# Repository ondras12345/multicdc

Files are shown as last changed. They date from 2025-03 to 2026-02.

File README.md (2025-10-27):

# MultiCDC
This is a simple RP2040-based 6-channel USB to UART converter.

This is my first project using the Zephyr RTOS, so there might be lots of
mistakes. However, it seems to work.

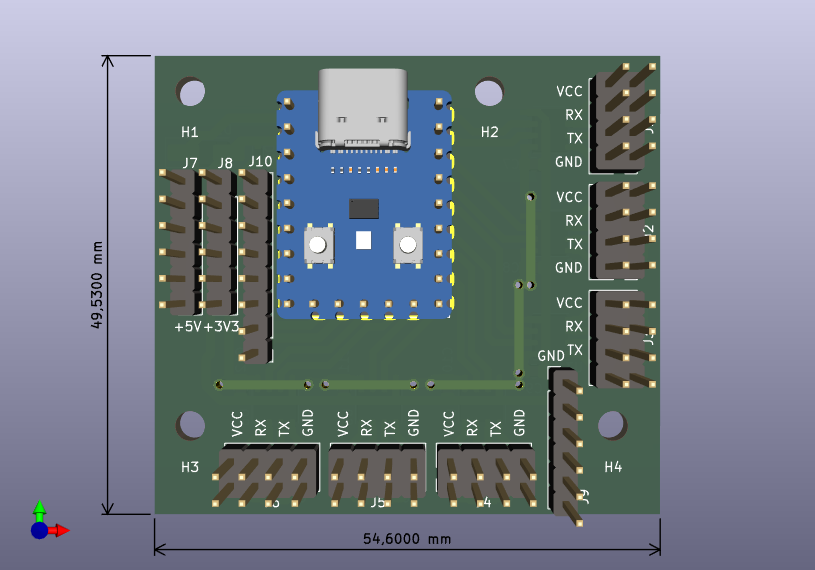
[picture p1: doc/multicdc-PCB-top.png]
top side of the MultiCDC pcb

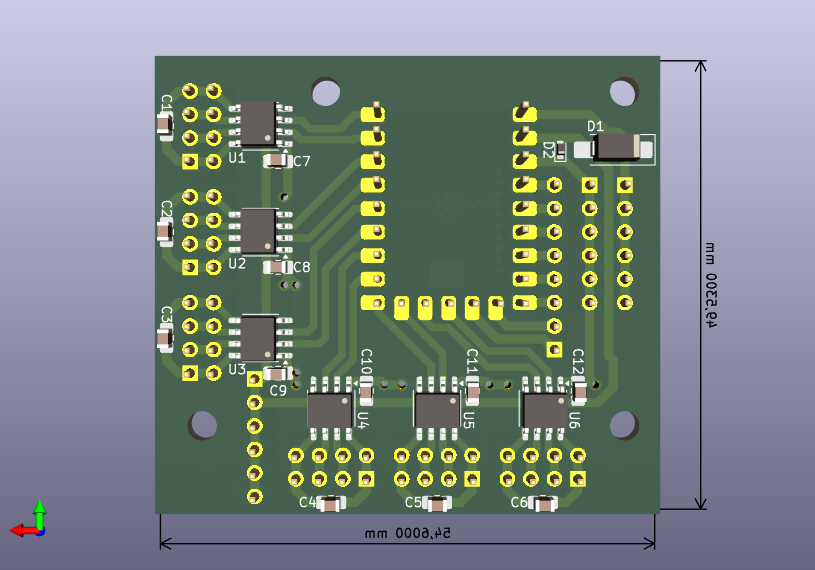
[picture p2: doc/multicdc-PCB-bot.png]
bottom side of the MultiCDC pcb


## Operation
The device creates 7 `/dev/ttyACM*` devices when connected to a linux host.
The first 6 are linked to hardware UARTs, and `/dev/ttyACM6` is used for
logging and shell.

The RP2040 only has 2 hardware UARTs. The other 4 channels use the PIOs.

Unfortunately, the `pico-uart-pio` driver doesn't allow changing the baud
rate at runtime. For this reason, baud rates (`current-speed`) for those
channels need to be set in the device tree (`app.overlay`).

Pin map (most of these can be changed arbitrarily):
| pin | function |
|:---:|:---:|
| P0  | Tx0 |
| P1  | Rx0 |
| P2  | Tx1 |
| P3  | Rx1 |
| P4  | Tx2 |
| P5  | Rx2 |
| P6  | Tx3 |
| P7  | Rx3 |
| P8  | Tx4 |
| P9  | Rx4 |
| P10 | Tx5 |
| P11 | Rx5 |

## Build
```sh
. ~/zephyrproject/.venv/bin/activate
. ~/zephyrproject/zephyr/zephyr-env.sh
west build

# enter bootloader: press BOOT button, press & release RESET, release BOOT
west flash
```

## Udev rules
```sh
sudo tee /etc/udev/rules.d/99-multicdc.rules > /dev/null << "EOF"
SUBSYSTEM=="tty", ENV{ID_VENDOR_ID}=="2fe3", ENV{ID_MODEL_ID}=="6cdc", ENV{ID_USB_INTERFACE_NUM}=="00", SYMLINK+="tty-mcdc0ch0"
SUBSYSTEM=="tty", ENV{ID_VENDOR_ID}=="2fe3", ENV{ID_MODEL_ID}=="6cdc", ENV{ID_USB_INTERFACE_NUM}=="02", SYMLINK+="tty-mcdc0ch1"
SUBSYSTEM=="tty", ENV{ID_VENDOR_ID}=="2fe3", ENV{ID_MODEL_ID}=="6cdc", ENV{ID_USB_INTERFACE_NUM}=="04", SYMLINK+="tty-mcdc0ch2"
SUBSYSTEM=="tty", ENV{ID_VENDOR_ID}=="2fe3", ENV{ID_MODEL_ID}=="6cdc", ENV{ID_USB_INTERFACE_NUM}=="06", SYMLINK+="tty-mcdc0ch3"
SUBSYSTEM=="tty", ENV{ID_VENDOR_ID}=="2fe3", ENV{ID_MODEL_ID}=="6cdc", ENV{ID_USB_INTERFACE_NUM}=="08", SYMLINK+="tty-mcdc0ch4"
SUBSYSTEM=="tty", ENV{ID_VENDOR_ID}=="2fe3", ENV{ID_MODEL_ID}=="6cdc", ENV{ID_USB_INTERFACE_NUM}=="0a", SYMLINK+="tty-mcdc0ch5"
SUBSYSTEM=="tty", ENV{ID_VENDOR_ID}=="2fe3", ENV{ID_MODEL_ID}=="6cdc", ENV{ID_USB_INTERFACE_NUM}=="0c", SYMLINK+="tty-mcdc0shell"
EOF

sudo udevadm control --reload-rules
sudo udevadm trigger
```

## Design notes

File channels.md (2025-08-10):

| channel | can change baudrate | baudrate  | voltage | device |
|:---:|:---:|---:|---:|:---|
| CH0 | yes | 38400 | 5V | lab-io (needs bootloader) |
| CH1 | no | 9600 | 5V | alarmclock |
| CH2 | yes | 115200 | ext | window-closer (bootloader)|
| CH3 | no | 9600 | 5V | ZPH02 |
| CH4 | no | 9600 | 3V3 | S88 (needs 5V power) |
| CH5 | no | 115200 | | reserved |

window-closer could teoretically go through a PIO channel now that we use
115200 baud both for the firmware and the bootloader, but avrdude upload via
pio was extremely unreliable.

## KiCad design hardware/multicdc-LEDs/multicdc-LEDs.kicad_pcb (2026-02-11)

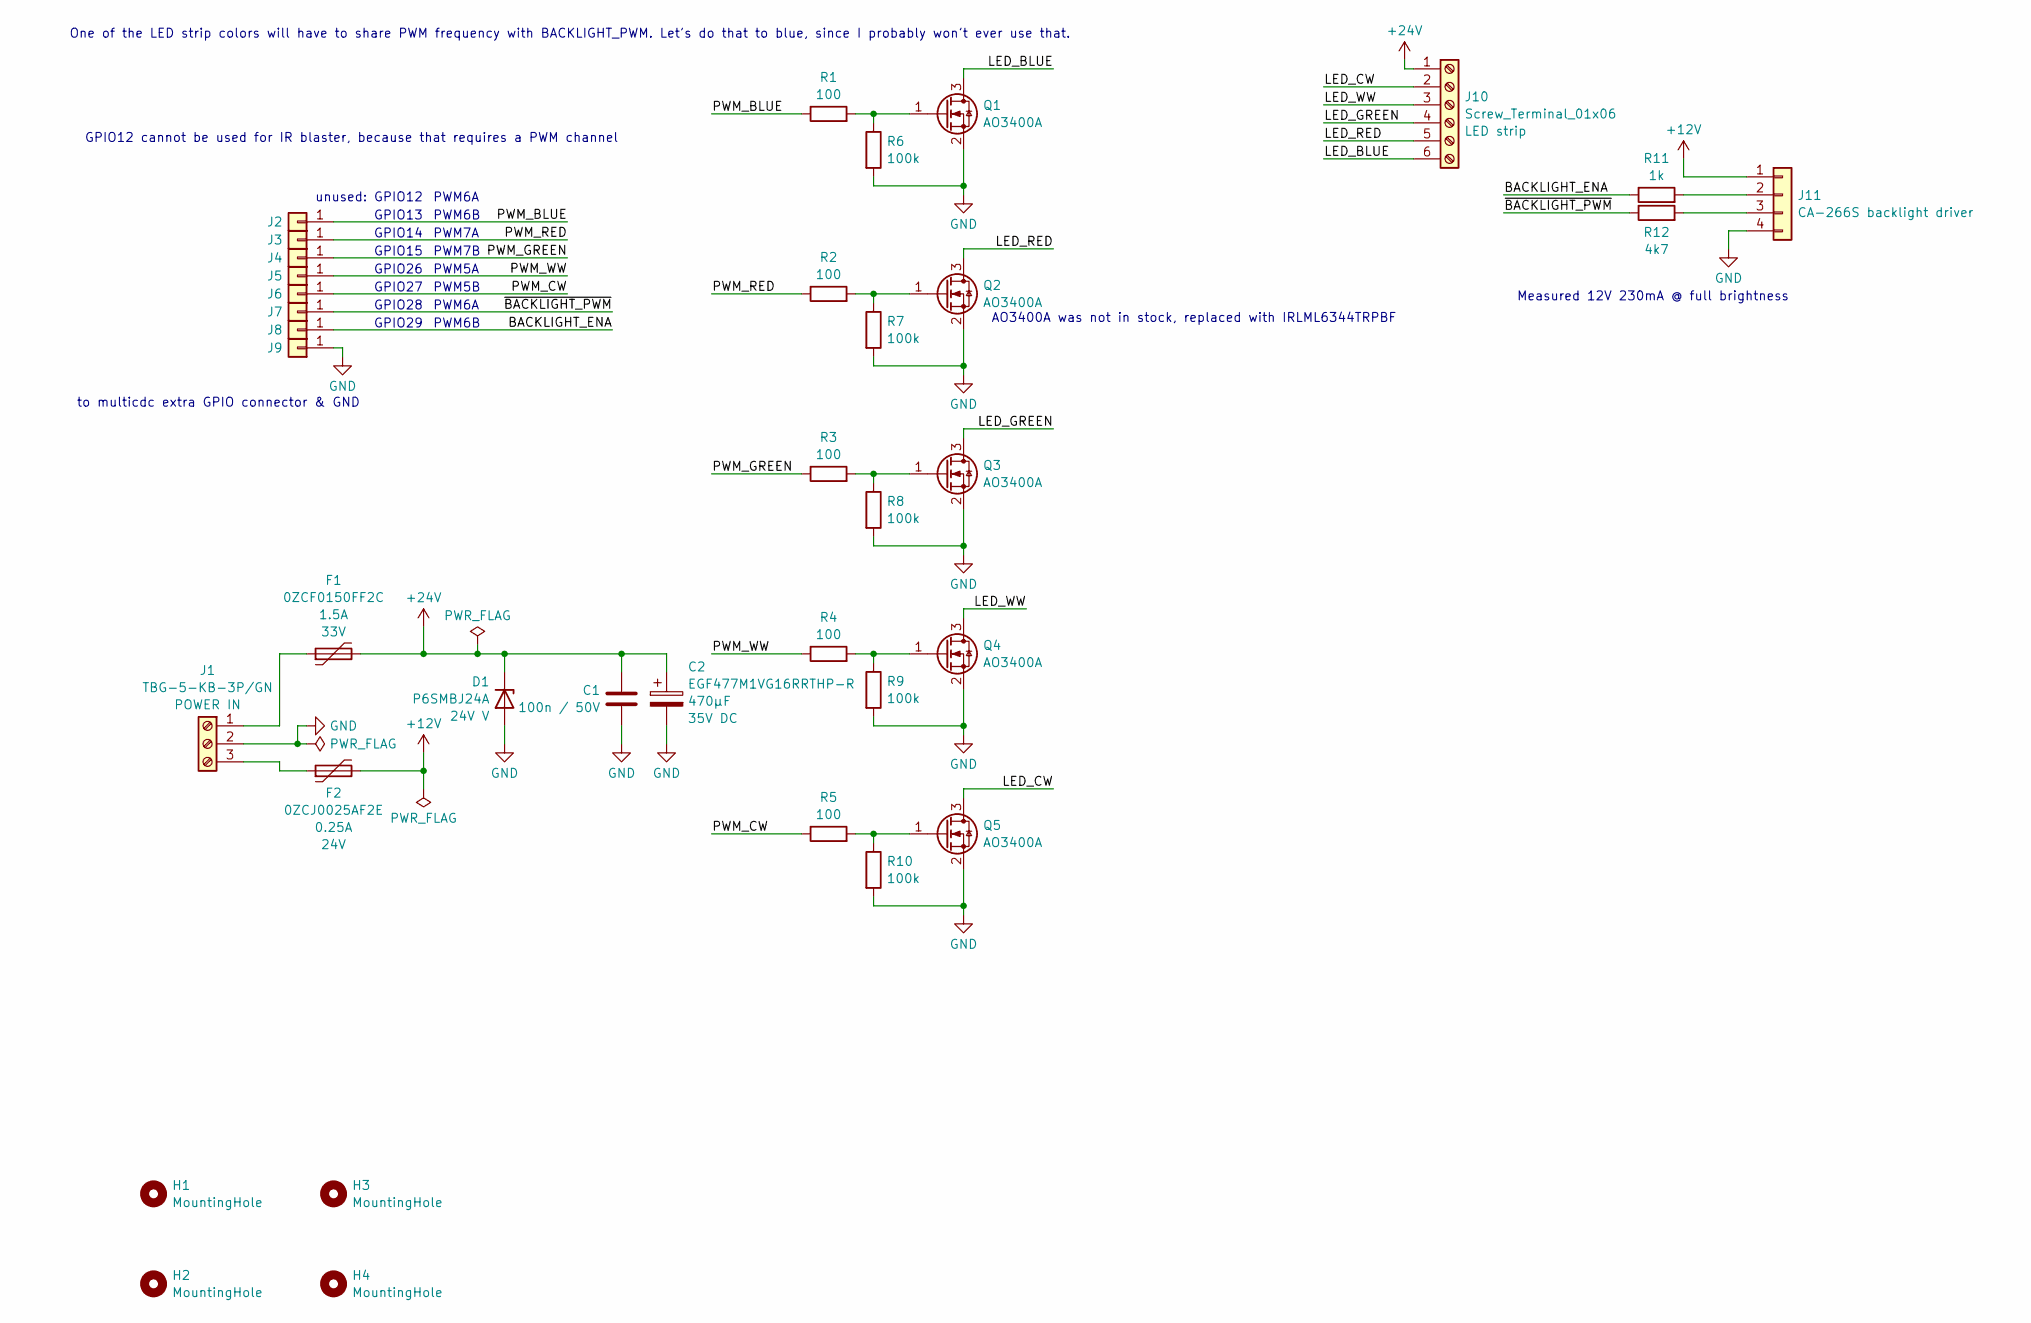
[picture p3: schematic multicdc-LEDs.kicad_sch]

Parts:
C1: 100n / 50V; C_1206_3216Metric_Pad1.33x1.80mm_HandSolder
C2: EGF477M1VG16RRTHP-R; CP_Radial_D10.0mm_P5.00mm; Tolerance 20% %; Rated Voltage 35V DC
D1: P6SMBJ24A; D_SMB_Handsoldering; Forward Voltage 26.7...29.6V; Standoff Voltage 24V V
F1: 0ZCF0150FF2C; Fuse_2920_7451Metric_Pad2.10x5.45mm_HandSolder; Rated Voltage 33V
F2: 0ZCJ0025AF2E; Fuse_1206_3216Metric_Pad1.42x1.75mm_HandSolder; Rated Voltage 24V
H1, H2, H3, H4: MountingHole; MountingHole_3.2mm_M3
J1: TBG-5-KB-3P/GN; TBG-5-KB-3P_1x03_P5.08mm_Horizontal; Rated Voltage 0.3kV
J2, J3, J4, J5, J6, J7, J8, J9: Conn_01x01; SolderWire-0.25sqmm_1x01_D0.65mm_OD1.7mm_Relief
J10: Screw_Terminal_01x06; TerminalBlock_Xinya_XY301VA-5.00-6P_1x06_P5.00mm_Horizontal
J11: soldered wires; SolderWire-0.25sqmm_1x04_P4.2mm_D0.65mm_OD1.7mm_Relief
Q1, Q2, Q3, Q4, Q5: AO3400A; SOT-23; Rated Voltage 30V
R1, R2, R3, R4, R5: 100; R_0805_2012Metric_Pad1.20x1.40mm_HandSolder
R6, R7, R8, R9, R10: 100k; R_0805_2012Metric_Pad1.20x1.40mm_HandSolder
R11: 1k; R_0805_2012Metric_Pad1.20x1.40mm_HandSolder
R12: 4k7; R_0805_2012Metric_Pad1.20x1.40mm_HandSolder

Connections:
+12V: F2.2, J11.1
+24V: C1.1, C2.1, D1.1 (K), F1.2, J10.1
/BACKLIGHT_ENA: J8.1, R11.1
/LED_BLUE: J10.6, Q1.3 (D)
/LED_CW: J10.2, Q5.3 (D)
/LED_GREEN: J10.4, Q3.3 (D)
/LED_RED: J10.5, Q2.3 (D)
/LED_WW: J10.3, Q4.3 (D)
/PWM_BLUE: J2.1, R1.1
/PWM_CW: J6.1, R5.1
/PWM_GREEN: J4.1, R3.1
/PWM_RED: J3.1, R2.1
/PWM_WW: J5.1, R4.1
/~BACKLIGHT_PWM: J7.1, R12.1
GND: C1.2, C2.2, D1.2 (A), J1.2, J9.1, J11.4, Q1.2 (S), Q2.2 (S), Q3.2 (S), Q4.2 (S), Q5.2 (S), R6.2, R7.2, R8.2, R9.2, R10.2
unnamed: F1.1, J1.1
unnamed: F2.1, J1.3
unnamed: J11.2, R11.2
unnamed: J11.3, R12.2
unnamed: Q1.1 (G), R1.2, R6.1
unnamed: Q2.1 (G), R2.2, R7.1
unnamed: Q3.1 (G), R3.2, R8.1
unnamed: Q4.1 (G), R4.2, R9.1
unnamed: Q5.1 (G), R5.2, R10.1

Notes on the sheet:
Measured 12V 230mA @ full brightness
GPIO15
GPIO27
GPIO29
GPIO26
unused: GPIO12
PWM5B
PWM6B
PWM7B
PWM5A
GPIO13
AO3400A was not in stock, replaced with IRLML6344TRPBF
One of the LED strip colors will have to share PWM frequency with BACKLIGHT_PWM. Let's do that to blue, since I probably won't ever use that.
to multicdc extra GPIO connector & GND
PWM7A
GPIO14
PWM6A
GPIO28
GPIO12 cannot be used for IR blaster, because that requires a PWM channel

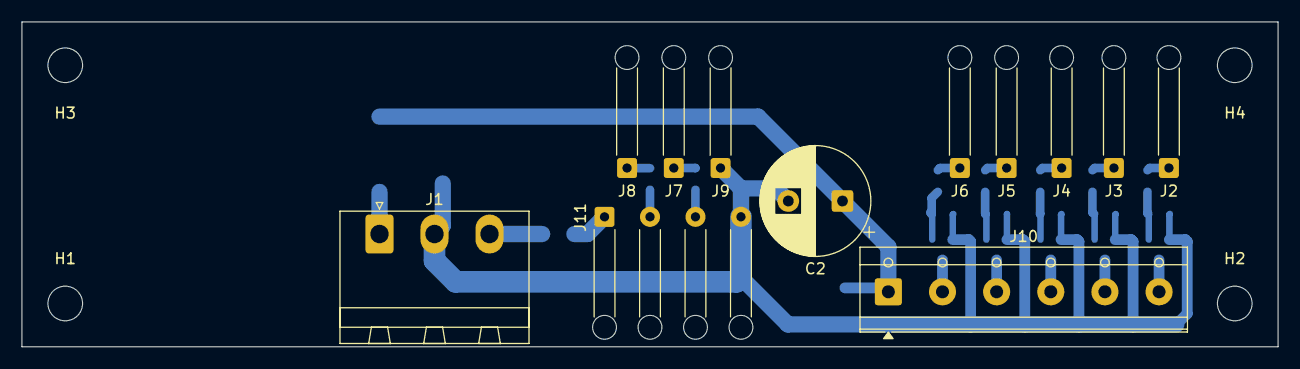
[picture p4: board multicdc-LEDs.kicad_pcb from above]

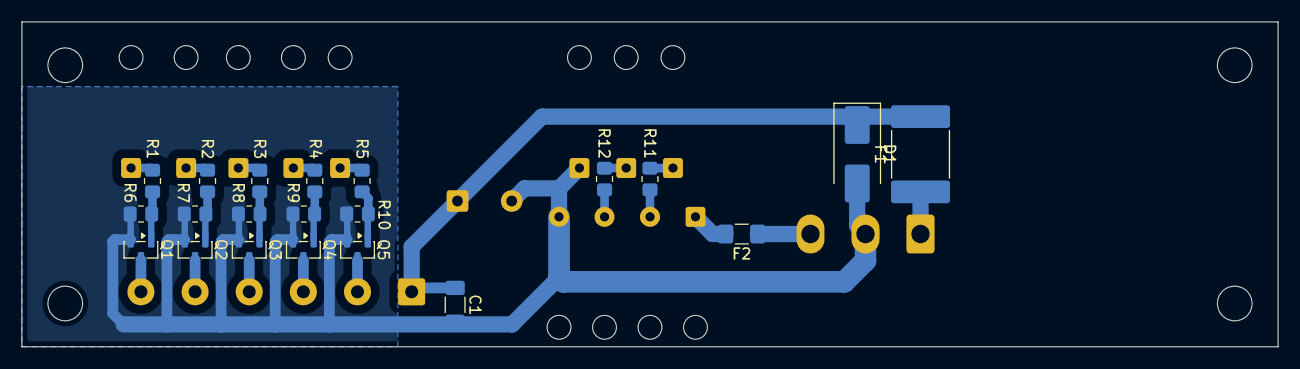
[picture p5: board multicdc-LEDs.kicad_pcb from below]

Board: 2 copper layers, 116.0 x 30.0 mm, 37 parts (21 on the bottom side), 24 nets.

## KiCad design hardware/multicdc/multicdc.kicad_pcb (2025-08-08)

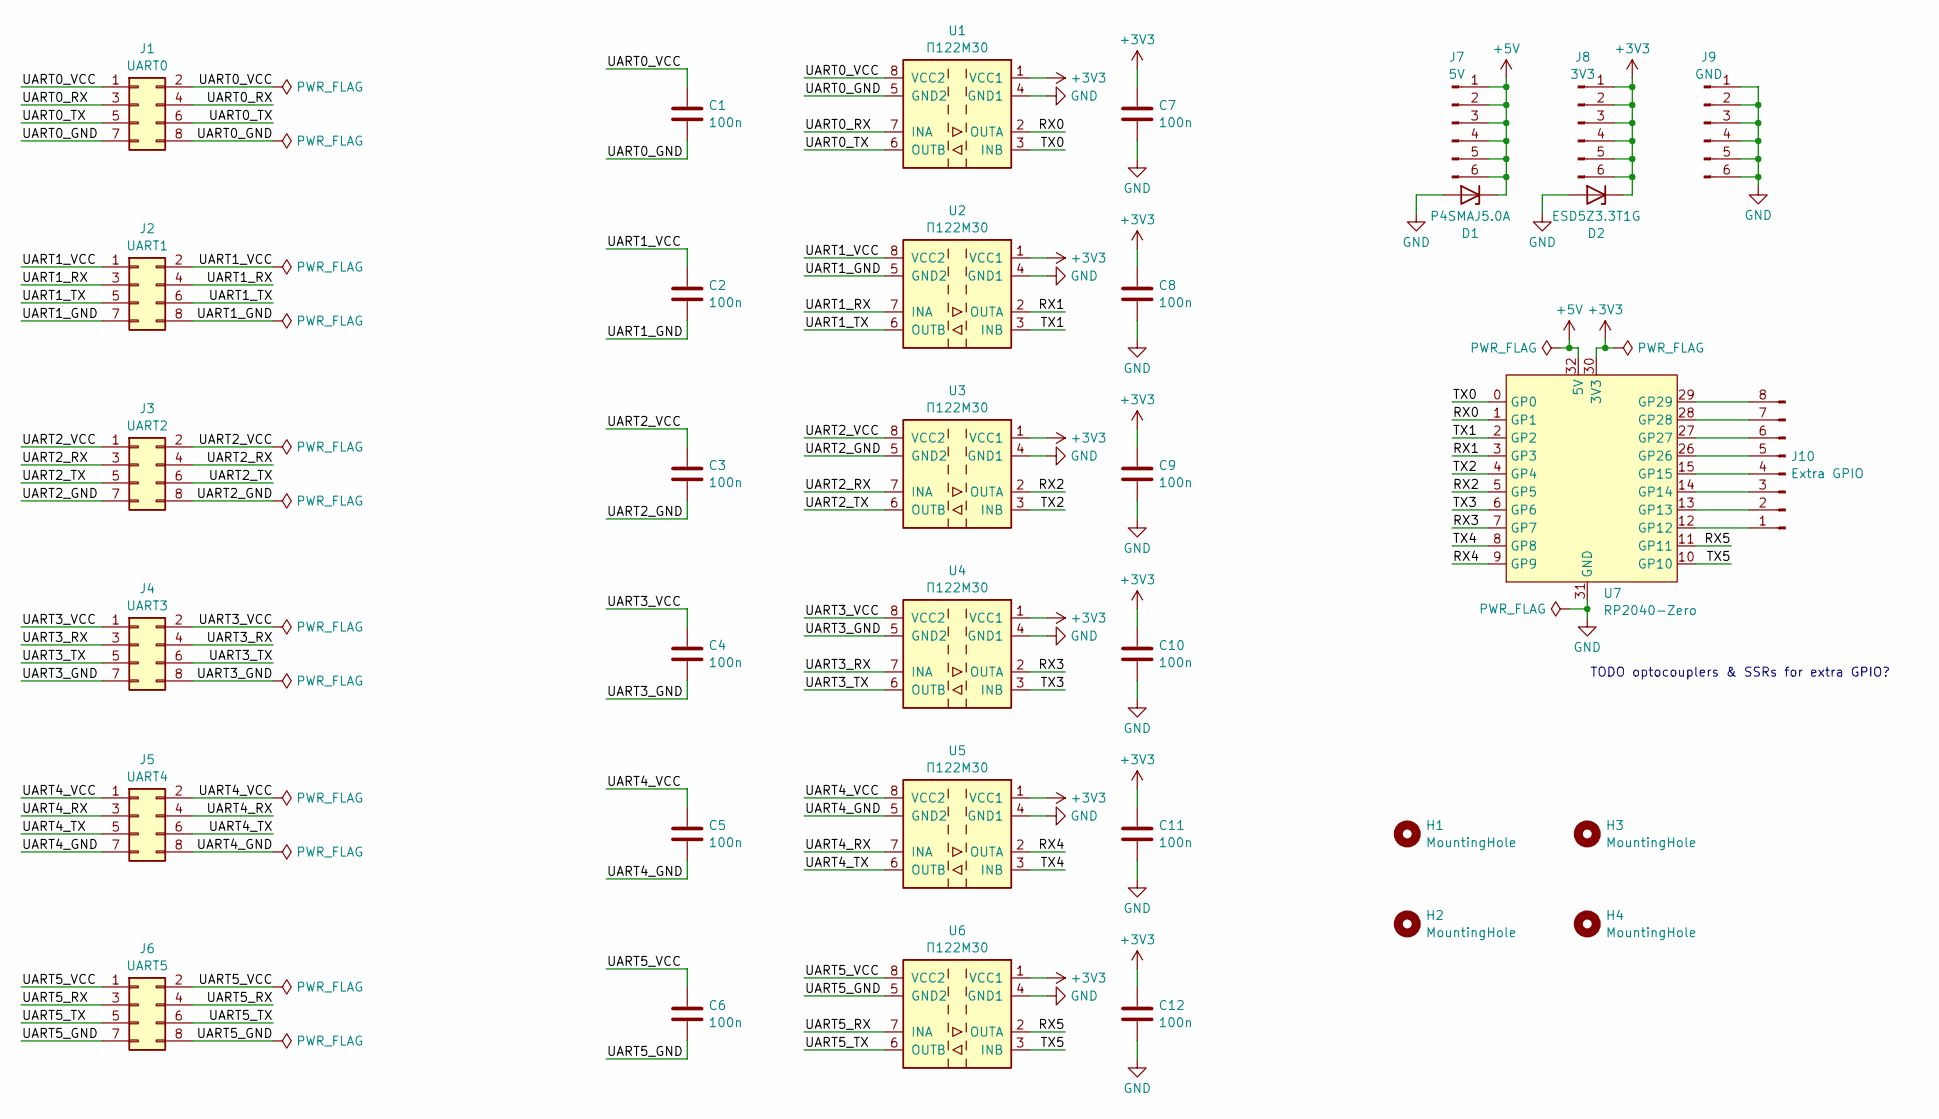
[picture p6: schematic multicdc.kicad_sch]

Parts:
C1, C2, C3, C4, C5, C6, C7, C8, C9, C10, C11, C12: 100n; C_0805_2012Metric_Pad1.18x1.45mm_HandSolder
D1: P4SMAJ5.0A; D_SMA_Handsoldering; Forward Voltage 6.4...7V; Standoff Voltage 5V
D2: ESD5Z3.3T1G; D_SOD-523; Forward Voltage 5V; Standoff Voltage 3.3V
H1, H2, H3, H4: MountingHole; MountingHole_3.2mm_M3
J1, J2, J3, J4, J5, J6: Conn_02x04_Odd_Even; PinHeader_2x04_P2.54mm_Vertical
J7, J8, J9: Conn_01x06_Pin; PinHeader_1x06_P2.54mm_Vertical
J10: Conn_01x08_Pin; PinHeader_1x08_P2.54mm_Vertical
U1, U2, U3, U4, U5, U6: Π122M30; SOIC-8_3.9x4.9mm_P1.27mm; Supply Voltage 3...5.5V DC
U7: RP2040-Zero

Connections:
+3V3: C7.1, C8.1, C9.1, C10.1, C11.1, C12.1, D2.1 (K), J8.1, J8.2, J8.3, J8.4, J8.5, J8.6, U1.1 (VCC1), U2.1 (VCC1), U3.1 (VCC1), U4.1 (VCC1), U5.1 (VCC1), U6.1 (VCC1), U7.30 (3V3)
+5V: D1.1 (K), J7.1, J7.2, J7.3, J7.4, J7.5, J7.6, U7.32 (5V)
/RX0: U1.2 (OUTA), U7.1 (GP1)
/RX1: U2.2 (OUTA), U7.3 (GP3)
/RX2: U3.2 (OUTA), U7.5 (GP5)
/RX3: U4.2 (OUTA), U7.7 (GP7)
/RX4: U5.2 (OUTA), U7.9 (GP9)
/RX5: U6.2 (OUTA), U7.11 (GP11)
/TX0: U1.3 (INB), U7.0 (GP0)
/TX1: U2.3 (INB), U7.2 (GP2)
/TX2: U3.3 (INB), U7.4 (GP4)
/TX3: U4.3 (INB), U7.6 (GP6)
/TX4: U5.3 (INB), U7.8 (GP8)
/TX5: U6.3 (INB), U7.10 (GP10)
/UART0_GND: C1.2, J1.7, J1.8, U1.5 (GND2)
/UART0_RX: J1.3, J1.4, U1.7 (INA)
/UART0_TX: J1.5, J1.6, U1.6 (OUTB)
/UART0_VCC: C1.1, J1.1, J1.2, U1.8 (VCC2)
/UART1_GND: C2.2, J2.7, J2.8, U2.5 (GND2)
/UART1_RX: J2.3, J2.4, U2.7 (INA)
/UART1_TX: J2.5, J2.6, U2.6 (OUTB)
/UART1_VCC: C2.1, J2.1, J2.2, U2.8 (VCC2)
/UART2_GND: C3.2, J3.7, J3.8, U3.5 (GND2)
/UART2_RX: J3.3, J3.4, U3.7 (INA)
/UART2_TX: J3.5, J3.6, U3.6 (OUTB)
/UART2_VCC: C3.1, J3.1, J3.2, U3.8 (VCC2)
/UART3_GND: C4.2, J4.7, J4.8, U4.5 (GND2)
/UART3_RX: J4.3, J4.4, U4.7 (INA)
/UART3_TX: J4.5, J4.6, U4.6 (OUTB)
/UART3_VCC: C4.1, J4.1, J4.2, U4.8 (VCC2)
/UART4_GND: C5.2, J5.7, J5.8, U5.5 (GND2)
/UART4_RX: J5.3, J5.4, U5.7 (INA)
/UART4_TX: J5.5, J5.6, U5.6 (OUTB)
/UART4_VCC: C5.1, J5.1, J5.2, U5.8 (VCC2)
/UART5_GND: C6.2, J6.7, J6.8, U6.5 (GND2)
/UART5_RX: J6.3, J6.4, U6.7 (INA)
/UART5_TX: J6.5, J6.6, U6.6 (OUTB)
/UART5_VCC: C6.1, J6.1, J6.2, U6.8 (VCC2)
GND: C7.2, C8.2, C9.2, C10.2, C11.2, C12.2, D1.2 (A), D2.2 (A), J9.1, J9.2, J9.3, J9.4, J9.5, J9.6, U1.4 (GND1), U2.4 (GND1), U3.4 (GND1), U4.4 (GND1), U5.4 (GND1), U6.4 (GND1), U7.31 (GND)
unnamed: J10.1, U7.12 (GP12)
unnamed: J10.2, U7.13 (GP13)
unnamed: J10.3, U7.14 (GP14)
unnamed: J10.4, U7.15 (GP15)
unnamed: J10.5, U7.26 (GP26)
unnamed: J10.6, U7.27 (GP27)
unnamed: J10.7, U7.28 (GP28)
unnamed: J10.8, U7.29 (GP29)

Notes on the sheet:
TODO optocouplers & SSRs for extra GPIO?

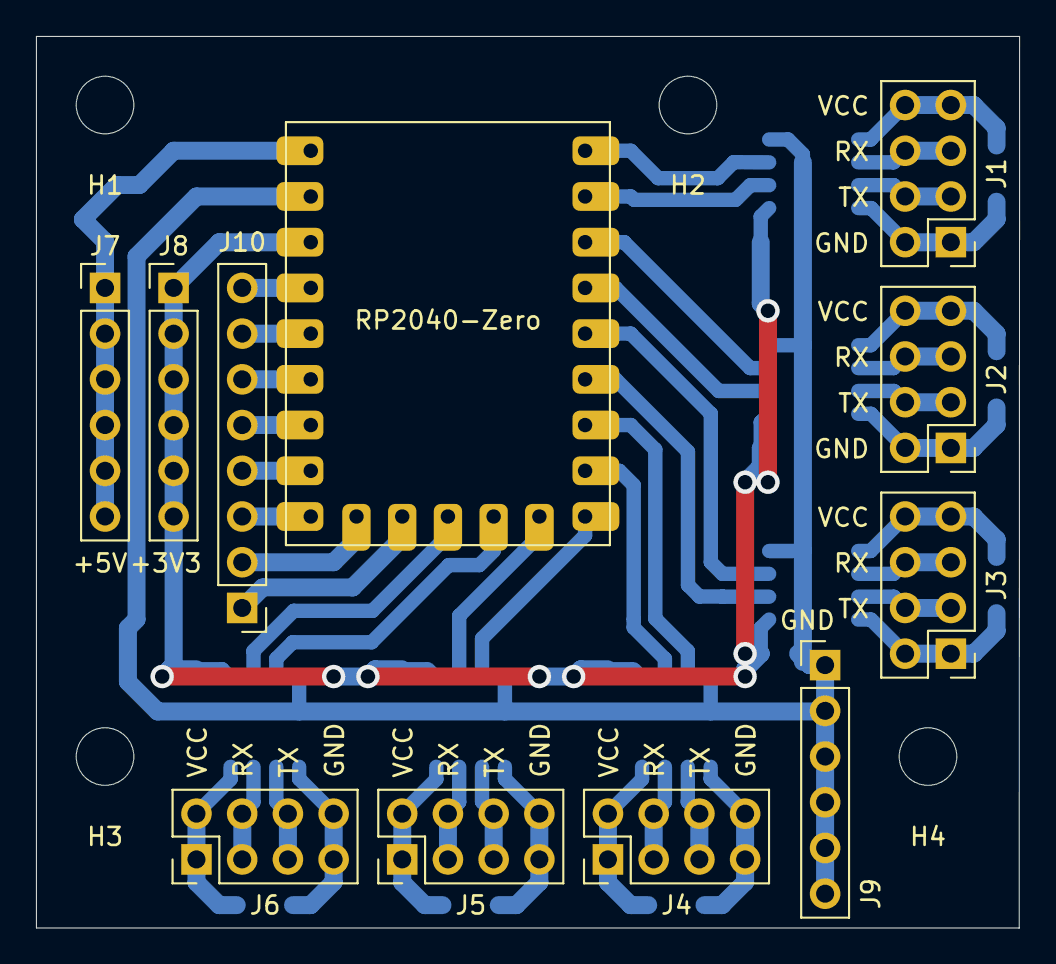
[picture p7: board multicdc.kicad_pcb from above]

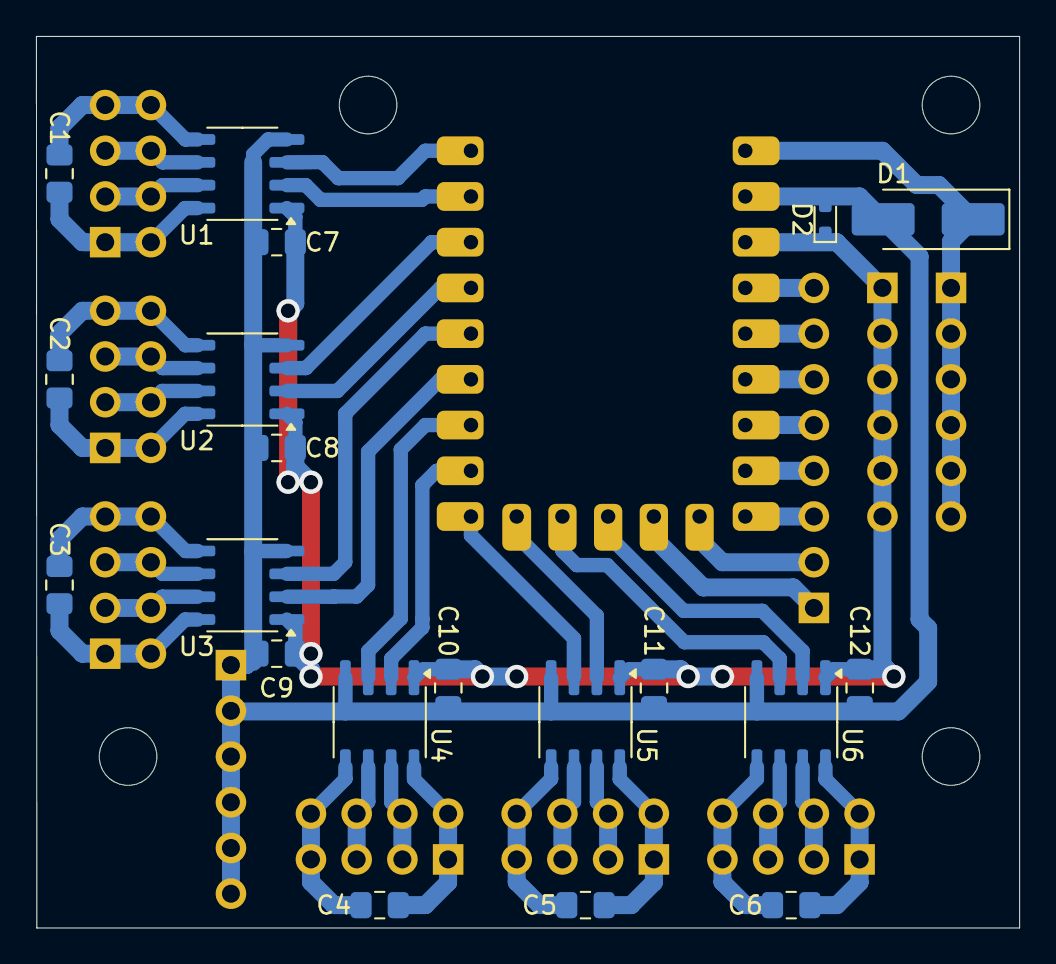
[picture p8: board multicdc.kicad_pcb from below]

Board: 2 copper layers, 54.6 x 49.5 mm, 35 parts (20 on the bottom side), 47 nets.

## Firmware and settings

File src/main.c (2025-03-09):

#include <stdio.h>
#include <stdlib.h>
#include <string.h>
#include <zephyr/device.h>
#include <zephyr/sys/printk.h>
#include <zephyr/drivers/uart.h>
#include <zephyr/kernel.h>
#include <zephyr/sys/ring_buffer.h>

#include <zephyr/usb/usb_device.h>
#include <zephyr/usb/usbd.h>
#include <zephyr/logging/log.h>

#include <zephyr/shell/shell.h>
#include <pico/bootrom.h>

#include <zephyr/drivers/watchdog.h>


BUILD_ASSERT(DT_NODE_HAS_COMPAT(DT_CHOSEN(zephyr_console), zephyr_cdc_acm_uart), "Console device is not ACM CDC UART device");

LOG_MODULE_REGISTER(multicdc, LOG_LEVEL_INF);

// We might not need this much (especially for non-CDC channels which can just
// pause reception on the CDC counterpart), but there's still a lot of RAM
// left.
#define RING_BUF_SIZE 10240

struct serial_channel {
    const struct device * dev;
    struct serial_channel * other;
    struct ring_buf rb;
    uint8_t buf[RING_BUF_SIZE];
    bool rx_throttled;
    uint8_t id;
};

struct serial_channel serial_channels[] = {
    // masters
    { .dev = DEVICE_DT_GET(DT_NODELABEL(cdc_acm_uart0)), },  // master 1
    { .dev = DEVICE_DT_GET(DT_NODELABEL(cdc_acm_uart1)), },
    { .dev = DEVICE_DT_GET(DT_NODELABEL(cdc_acm_uart2)), },
    { .dev = DEVICE_DT_GET(DT_NODELABEL(cdc_acm_uart3)), },
    { .dev = DEVICE_DT_GET(DT_NODELABEL(cdc_acm_uart4)), },
    { .dev = DEVICE_DT_GET(DT_NODELABEL(cdc_acm_uart5)), },
    // slaves
    { .dev = DEVICE_DT_GET(DT_NODELABEL(uart0)), },  // slave 1
    { .dev = DEVICE_DT_GET(DT_NODELABEL(pio0_uart0)), },
    { .dev = DEVICE_DT_GET(DT_NODELABEL(uart1)), },
    { .dev = DEVICE_DT_GET(DT_NODELABEL(pio0_uart1)), },
    { .dev = DEVICE_DT_GET(DT_NODELABEL(pio1_uart0)), },
    { .dev = DEVICE_DT_GET(DT_NODELABEL(pio1_uart1)), },
    // Master n is connected to slave n.
};

const unsigned n_ch_pairs = ARRAY_SIZE(serial_channels)/2;
uint16_t polling_channels = 0x00;

// thread stacks cannot be allocated dynamically on the heap
K_THREAD_STACK_DEFINE(stack_1, 256);
K_THREAD_STACK_DEFINE(stack_2, 256);
K_THREAD_STACK_DEFINE(stack_3, 256);
K_THREAD_STACK_DEFINE(stack_4, 256);

k_thread_stack_t * stacks[] = {
    stack_1,
    stack_2,
    stack_3,
    stack_4,
    NULL
};

unsigned stack_sizes[] = {
    K_THREAD_STACK_SIZEOF(stack_1),
    K_THREAD_STACK_SIZEOF(stack_2),
    K_THREAD_STACK_SIZEOF(stack_3),
    K_THREAD_STACK_SIZEOF(stack_4),
};

struct k_thread thread_datas[4];

const struct device *const wdt = DEVICE_DT_GET(DT_ALIAS(watchdog0));


static void interrupt_handler(const struct device *dev, void *user_data)
{
    struct serial_channel * channel = user_data;

    while (uart_irq_update(dev) && uart_irq_is_pending(dev))
    {
        if (!channel->rx_throttled && uart_irq_rx_ready(dev))
        {
            struct ring_buf *rb = &channel->other->rb;

            uint8_t buffer[64];
            size_t len = MIN(ring_buf_space_get(rb), sizeof(buffer));

            if (len == 0)
            {
                LOG_DBG("ch %u: throttling rx", channel->id);
                channel->rx_throttled = true;
                uart_irq_rx_disable(dev);
            }

            int recv_len = uart_fifo_read(dev, buffer, len);
            LOG_DBG("ch %u: ISR rx %u bytes", channel->id, recv_len);
            if (recv_len < 0) {
                LOG_ERR("ch %u: failed to read UART FIFO", channel->id);
                recv_len = 0;
            };

            int rb_len = ring_buf_put(rb, buffer, recv_len);
            if (rb_len < recv_len) {
                LOG_ERR("ch %u: ISR rx drop %u bytes", channel->id, recv_len - rb_len);
            }

            if (rb_len) {
                uart_irq_tx_enable(channel->other->dev);
            }
        }

        if (uart_irq_tx_ready(dev))
        {
            uint8_t buffer[64];  // max packet size for CDC

            int rb_len = ring_buf_peek(&channel->rb, buffer, sizeof(buffer));

            if (!rb_len) {
                LOG_DBG("ch %u: ring buffer empty, disable TX IRQ", channel->id);
                uart_irq_tx_disable(dev);
                continue;
            }

            int send_len = uart_fifo_fill(dev, buffer, rb_len);
            LOG_DBG("ch %u: ISR tx %u bytes", channel->id, send_len);
            // actually remove the bytes from the ring buffer
            ring_buf_get(&channel->rb, buffer, send_len);
            // allow further rx
            if (channel->other->rx_throttled)
            {
                LOG_DBG("ch %u: unthrottling rx", channel->other->id);
                channel->other->rx_throttled = false;
                uart_irq_rx_enable(channel->other->dev);
            }
        }
    }
}


void polling_timer_handler(struct k_timer *dummy)
{
    ARG_UNUSED(dummy);

    for (unsigned i = 0; i < ARRAY_SIZE(serial_channels); i++)
    {
        const struct serial_channel * channel = &serial_channels[i];
        if (!(polling_channels & (1<<i))) continue;
        // receive everything from this channel
        char c;
        size_t bytes_read = 0;
        while (!uart_poll_in(channel->dev, &c))
        {
            bytes_read++;
            LOG_DBG("ch %u: rx 1 byte '%c'", channel->id, c);
            if (ring_buf_put(&channel->other->rb, &c, 1))
            {
                uart_irq_tx_enable(channel->other->dev);
            }
            // There's no good way around dropping the byte,
            // the rx FIFO is extremely short.
            else LOG_ERR("ch %u: rx drop 1 byte", channel->id);
        }
        if (bytes_read > 2)
        {
            LOG_WRN("ch %u: rx >2 bytes, FIFO overrun possible", channel->id);
        }
    }
}

K_TIMER_DEFINE(polling_timer, polling_timer_handler, NULL);


/// thread entry point for polling uart
void polling_echo(void * p1, void * p2, void * p3)
{
    struct serial_channel * channel = p1;
    ARG_UNUSED(p2);
    ARG_UNUSED(p3);

    for (;;)
    {
        // uart_poll_out is a blocking call, hence the need for a separate
        // thread
        char c;
        while (ring_buf_get(&channel->rb, &c, 1))
        {
            if (channel->other->rx_throttled)
            {
                LOG_DBG("ch %u: unthrottling rx", channel->id);
                channel->other->rx_throttled = false;
                uart_irq_rx_enable(channel->other->dev);
            }

            LOG_DBG("ch %u: tx 1 byte '%c'", channel->id, c);
            uart_poll_out(channel->dev, c);
        }
        // If we fall out of the while loop, there is nothing to tx, and
        // there's no blocking call in the loop.
        // We need to yield to let other threads do their thing.
        k_sleep(K_USEC(50));
    }
}


static int cmd_bootload(const struct shell *sh, size_t argc, char **argv)
{
    wdt_disable(wdt);  // TODO is this needed?
    shell_print(sh, "jumping to bootloader");
    k_sleep(K_MSEC(500));
    // TODO this sometimes fails
    reset_usb_boot(0, 0);
    return 0;
}

SHELL_CMD_ARG_REGISTER(bootload, NULL, "jump to bootloader", cmd_bootload, 1, 0);

int main(void)
{
    if (!device_is_ready(wdt)) {
        printk("%s: device not ready.\n", wdt->name);
        return 0;
    }
    struct wdt_timeout_cfg wdt_config = {
        /* Reset SoC when watchdog timer expires. */
        .flags = WDT_FLAG_RESET_SOC,

        /* Expire watchdog after max window */
        .window.min = 0U,
        .window.max = 2000U,
    };
    int wdt_channel_id = wdt_install_timeout(wdt, &wdt_config);
    if (wdt_channel_id < 0)
    {
        LOG_ERR("watchdog install error");
        return 0;
    }

    if (wdt_setup(wdt, 0) < 0)
    {
        LOG_ERR("watchdog setup error");
        return 0;
    }

    wdt_feed(wdt, wdt_channel_id);

    if (usb_enable(NULL)) {
        LOG_ERR("Failed to enable USB");
        return 0;
    }

    for (unsigned i = 0; i < ARRAY_SIZE(serial_channels); i++)
    {
        serial_channels[i].id = i;
        if (!device_is_ready(serial_channels[i].dev)) {
            LOG_ERR("ch %d not ready", i);
            return 0;
        }

        ring_buf_init(&serial_channels[i].rb, sizeof(serial_channels[i].buf), serial_channels[i].buf);
    }

    // connect channels to each other
    for (unsigned i = 0; i < n_ch_pairs; i++)
    {
        serial_channels[i].other = &serial_channels[n_ch_pairs+i];
        serial_channels[n_ch_pairs+i].other = &serial_channels[i];
    }

    /* Wait 100ms for the host to do all settings */
    //k_msleep(100);

    for (unsigned i = 0; i < ARRAY_SIZE(serial_channels); i++)
    {
        int ret = uart_irq_callback_user_data_set(serial_channels[i].dev, interrupt_handler, &serial_channels[i]);
        // pio uart does not support interrupt API
        if (ret) polling_channels |= (1<<i);
    }

    LOG_WRN("channels do not support interrupts: %x", polling_channels);

    unsigned stack_id = 0;
    for (unsigned i = 0; i < ARRAY_SIZE(serial_channels); i++)
    {
        const struct serial_channel * channel = &serial_channels[i];
        if (polling_channels & (1<<i))
        {
            LOG_INF("creating thread for channel %i", i);
            if (stacks[stack_id] == NULL)
            {
                LOG_ERR("ran out of stacks for thread");
                k_sleep(K_MSEC(5));
                return 0;
            }

            k_thread_create(&thread_datas[stack_id], stacks[stack_id],
                    stack_sizes[stack_id],
                    polling_echo, (void *)channel, NULL, NULL,
                    2 /* priority */, 0, K_NO_WAIT);
            stack_id++;
        }
        else
        {
            /* Enable rx interrupts */
            uart_irq_rx_enable(channel->dev);
        }
    }

    /* start polling rx timer */
    /* 50 us should be frequent enough @ 115200 baud */
    k_timer_start(&polling_timer, K_USEC(50), K_USEC(50));

    for (;;)
    {
        // set the correct baud rate on all port pairs
        for (unsigned i = 0; i < n_ch_pairs; i++)
        {
            const struct device * master_dev = serial_channels[i].dev;
            const struct device * slave_dev = serial_channels[n_ch_pairs+i].dev;

            uint32_t baudrate;
            int ret = uart_line_ctrl_get(master_dev, UART_LINE_CTRL_BAUD_RATE, &baudrate);
            if (ret) {
                LOG_WRN("Failed to get baudrate, ret code %d", ret);
                continue;
            }

            struct uart_config cfg;
            // TODO pio UARTs don't support setting baudrate at runtime
            if ((ret = uart_config_get(slave_dev, &cfg)))
            {
                //LOG_WRN("Failed to get UART config on channel %d, ret code %d", i, ret);
                continue;
            }
            if (baudrate != cfg.baudrate)
            {
                LOG_INF("changing baud rate on channel %d to %u", i, baudrate);
                cfg.baudrate = baudrate;
                if ((ret = uart_configure(slave_dev, &cfg)))
                {
                    LOG_ERR("Failed to set UART config on channel %d, ret code %d", i, ret);
                    continue;
                }
            }
        }

        wdt_feed(wdt, wdt_channel_id);
        k_sleep(K_MSEC(10));
    }

    return 0;
}

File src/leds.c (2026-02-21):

/*
 * Led strip control from Home Assistant via modbus. Heavily inspired by
 * zephyr/samples/subsys/modbus/rtu_server.
 */

#include <stdlib.h>
#include <zephyr/kernel.h>
#include <zephyr/device.h>
#include <zephyr/logging/log.h>
#include <zephyr/drivers/gpio.h>
#include <zephyr/drivers/pwm.h>
#include <zephyr/shell/shell.h>

LOG_MODULE_REGISTER(multicdc_leds, LOG_LEVEL_DBG);

K_SEM_DEFINE(leds_transition_sem, 0, 1);

#define LEDS_STACK 512
#define LEDS_PRIO 10  // lower priority than uart
#define TRANSITION_PERIOD_MS 15

#define MODBUS_NODE DT_COMPAT_GET_ANY_STATUS_OKAY(zephyr_modbus_serial)

// see tools/leds_gamma.py
static const uint16_t gamma255_65535[] = {
    0, 0, 0, 0, 1, 1, 2, 3, 4, 6, 8, 10, 13, 16, 19, 24, 28, 33, 39, 46, 53, 60, 69, 78, 88, 98, 110, 122, 135, 149, 164, 179, 196, 214, 232, 252, 273, 295, 317, 341, 366, 393, 420, 449, 478, 510, 542, 575, 610, 647, 684, 723, 764, 806, 849, 894, 940, 988, 1037, 1088, 1140, 1194, 1250, 1307, 1366, 1427, 1489, 1553, 1619, 1686, 1756, 1827, 1900, 1975, 2051, 2130, 2210, 2293, 2377, 2463, 2552, 2642, 2734, 2829, 2925, 3024, 3124, 3227, 3332, 3439, 3548, 3660, 3774, 3890, 4008, 4128, 4251, 4376, 4504, 4634, 4766, 4901, 5038, 5177, 5319, 5464, 5611, 5760, 5912, 6067, 6224, 6384, 6546, 6711, 6879, 7049, 7222, 7397, 7576, 7757, 7941, 8128, 8317, 8509, 8704, 8902, 9103, 9307, 9514, 9723, 9936, 10151, 10370, 10591, 10816, 11043, 11274, 11507, 11744, 11984, 12227, 12473, 12722, 12975, 13230, 13489, 13751, 14017, 14285, 14557, 14833, 15111, 15393, 15678, 15967, 16259, 16554, 16853, 17155, 17461, 17770, 18083, 18399, 18719, 19042, 19369, 19700, 20034, 20372, 20713, 21058, 21407, 21759, 22115, 22475, 22838, 23206, 23577, 23952, 24330, 24713, 25099, 25489, 25884, 26282, 26683, 27089, 27499, 27913, 28330, 28752, 29178, 29608, 30041, 30479, 30921, 31367, 31818, 32272, 32730, 33193, 33660, 34131, 34606, 35085, 35569, 36057, 36549, 37046, 37547, 38052, 38561, 39075, 39593, 40116, 40643, 41175, 41711, 42251, 42796, 43346, 43899, 44458, 45021, 45588, 46161, 46737, 47319, 47905, 48495, 49091, 49691, 50295, 50905, 51519, 52138, 52761, 53390, 54023, 54661, 55303, 55951, 56604, 57261, 57923, 58590, 59262, 59939, 60621, 61308, 62000, 62697, 63399, 64106, 64818, 65535
};

struct led_transition {
    // hardware configuration
    const struct pwm_dt_spec * const led_pwm;  //< PWM channel
    const struct gpio_dt_spec * const led_power;  //< power switch. Can be NULL.

    // internal state
    uint8_t brightness; //< current brightness
    uint8_t target;     //< target brightness
    uint8_t start;      //< start brightness (captured at set())
    uint32_t duration_ms; //< total transition duration
    uint32_t elapsed_ms;  //< elapsed time
    bool active;
};

void led_transition_start(struct led_transition * t, uint8_t target, uint32_t duration_ms)
{
    if (!t) return;

    t->start = t->brightness;
    t->target = target;
    t->duration_ms = duration_ms;
    t->elapsed_ms = 0;

    if (t->start == t->target) {
        t->active = false;
        return;
    }

    t->active = true;

    // turn the power on
    if (t->led_power && (t->start > 0 || t->target > 0)) {
        int r = gpio_pin_set_dt(t->led_power, 1);
        if (r) LOG_ERR("error setting GPIO high: %d", r);
    }

    // unblock transition loop
    k_sem_give(&leds_transition_sem);
}

void led_transition_apply_brightness(struct led_transition * t)
{
    if (!t || !t->led_pwm) return;
    // gamma-compensated brightness 0-65535
    uint16_t o = gamma255_65535[t->brightness];
    // set led brightness
    uint32_t pulse = (uint64_t)t->led_pwm->period * o / 65535;
    pwm_set_pulse_dt(t->led_pwm, pulse);
}

/**
 * Execute LED brightness transition. To be called every TRANSITION_PERIOD_MS.
 * @retval true if still running
 * @retval false if finished / not active
 */
bool led_transition_step(struct led_transition * t)
{
    if (!t || !t->active) return false;

    uint64_t elapsed = t->elapsed_ms + TRANSITION_PERIOD_MS;

    if (elapsed >= t->duration_ms) {
        // finish
        t->elapsed_ms = t->duration_ms;
        t->brightness = t->target;
        led_transition_apply_brightness(t);
        t->active = false;
        if (t->brightness == 0 && t->led_power) {
            int r = gpio_pin_set_dt(t->led_power, 0);
            if (r) LOG_ERR("error setting GPIO low: %d", r);
        }
        return false;
    }

    t->elapsed_ms = elapsed;

    // Interpolate: b = start + (target-start) * elapsed / duration
    int16_t delta = (int16_t)t->target - (int16_t)t->start;

    int64_t num = delta * (int64_t)t->elapsed_ms;
    int64_t den = t->duration_ms;
    // round-to-nearest
    int64_t adj = (num >= 0) ? (den / 2u) : -(den / 2u);
    int64_t b = (int64_t)t->start + (num + adj) / den;
    uint8_t next = CLAMP(b, 0, 255);

    if (next != t->brightness) {
        t->brightness = next;
        led_transition_apply_brightness(t);
    }
    return true;
}


static const struct pwm_dt_spec led_rgbcct_r = PWM_DT_SPEC_GET(DT_NODELABEL(pwm_led_rgbcct_r));
static const struct pwm_dt_spec led_rgbcct_g = PWM_DT_SPEC_GET(DT_NODELABEL(pwm_led_rgbcct_g));
static const struct pwm_dt_spec led_rgbcct_b = PWM_DT_SPEC_GET(DT_NODELABEL(pwm_led_rgbcct_b));
static const struct pwm_dt_spec led_rgbcct_c = PWM_DT_SPEC_GET(DT_NODELABEL(pwm_led_rgbcct_c));
static const struct pwm_dt_spec led_rgbcct_w = PWM_DT_SPEC_GET(DT_NODELABEL(pwm_led_rgbcct_w));
static const struct pwm_dt_spec led_backlight = PWM_DT_SPEC_GET(DT_NODELABEL(pwm_led_backlight));
static const struct gpio_dt_spec gpio_backlight_enable = GPIO_DT_SPEC_GET(DT_NODELABEL(led_backlight_enable), gpios);

static struct led_transition tran_rgbcct_r = {
    .led_pwm = &led_rgbcct_r,
};

static struct led_transition tran_rgbcct_g = {
    .led_pwm = &led_rgbcct_g,
};

static struct led_transition tran_rgbcct_b = {
    .led_pwm = &led_rgbcct_b,
};

static struct led_transition tran_rgbcct_c = {
    .led_pwm = &led_rgbcct_c,
};

static struct led_transition tran_rgbcct_w = {
    .led_pwm = &led_rgbcct_w,
};

static struct led_transition tran_backlight = {
    .led_pwm = &led_backlight,
    .led_power = &gpio_backlight_enable,
};


static struct led_transition * led_transitions[] = {
    &tran_rgbcct_r,
    &tran_rgbcct_g,
    &tran_rgbcct_b,
    &tran_rgbcct_c,
    &tran_rgbcct_w,
    &tran_backlight,
};
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

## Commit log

2025-03-09 Remove dependency on zephyr samples
2025-03-12 Improve pin map
2025-03-12 Fix typo in Rx5 pin name in README
2025-03-14 Add hardware designs
    [multicdc.kicad_pcb, multicdc.kicad_sch]
2025-03-15 Finish hardware designs
    [multicdc.kicad_pcb, multicdc.kicad_sch]
2025-03-20 Fix Kconfig copied from sample
    As far as I can tell, this didn't actually cause any trouble.
2025-08-08 Add note to PCB
    [multicdc.kicad_pcb]
2025-10-27 Add PCB renders to README
2026-02-11 Add multicdc-LEDs PCB design
    [multicdc-LEDs.kicad_pcb, multicdc-LEDs.kicad_sch]
2026-02-11 Implement LED control
2026-02-11 Improve LED PWM resolution
2026-02-13 Add tools/leds_gamma.py
2026-02-13 Implement MQTT LED control
2026-02-21 Fix LEDs GPIO control
    [leds.c]
2026-02-21 Fix backlight ON command
    [multicdc2mqtt.py]
2026-02-21 Report color temperatures in discovery message
